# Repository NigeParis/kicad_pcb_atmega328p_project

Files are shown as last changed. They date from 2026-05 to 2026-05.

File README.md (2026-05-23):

# Schematic Bill of Materials

| Reference | Qty | Value | Footprint | Datasheet |
|---|-----|---|---|---|
| C1, C2 | 2 | 12 pF | SMD_603 | [Yageo X7R](https://yageogroup.com/content/datasheet/asset/file/UPY-GPHC_X7R_6_3V-TO-250V) |
| C3 | 1 | 100 nF | SMD_603 | [Yageo X7R](https://yageogroup.com/content/datasheet/asset/file/UPY-GPHC_X7R_6_3V-TO-250V) |
| C4, C7 | 2 | 100 nF | SMD_603 | [Yageo X7R](https://yageogroup.com/content/datasheet/asset/file/UPY-GPHC_X7R_6_3V-TO-250V) |
| C6 | 1 | 1 µF | SMD_603 | [Yageo X7R](https://yageogroup.com/content/datasheet/asset/file/UPY-GPHC_X7R_6_3V-TO-250V) |
| D1 | 1 | LED Green | SMD_603 | [KP-1608ID](https://cdn-reichelt.de/documents/datenblatt/A500/KP-1608ID(VER.9A).pdf) |
| D2 | 1 | LED Red | SMD_603 | [KP-1608ID](https://cdn-reichelt.de/documents/datenblatt/A500/KP-1608ID(VER.9A).pdf) |
| J1 | 1 | Connector | J1_connector | [Samtec TSW](https://suddendocs.samtec.com/catalog_english/tsw_th.pdf) |
| J2 | 1 | Connector | J2_connector | [Samtec TSW](https://suddendocs.samtec.com/catalog_english/tsw_th.pdf) |
| J3 | 1 | FTDI | TSW-106-08-L-S-RA | [Samtec TSW](https://suddendocs.samtec.com/catalog_english/tsw_th.pdf) |
| R1 | 1 | 330 Ω | SMD_603 | [Yageo RC](https://yageogroup.com/content/datasheet/asset/file/PYU-RC_GROUP_51_ROHS_L) |
| R2, R3 | 2 | 10 kΩ | SMD_603 | [Yageo RC](https://yageogroup.com/content/datasheet/asset/file/PYU-RC_GROUP_51_ROHS_L) |
| SW1 | 1 | Push Switch | B3U-1000P(M) | [Omron B3U](https://omronfs.omron.com/en_US/ecb/products/pdf/en-b3u.pdf) |
| U1 | 1 | ATmega328P-A | TQFP-32 | [Microchip](https://ww1.microchip.com/downloads/aemDocuments/documents/corporate-responsibilty/environmental/material-compliance-documents/32L_TQFP_7x7x1_0mm_PT_C04-00074c.pdf) |
| Y1 | 1 | 16 MHz Crystal | SMD3225-4P | [X322516MLB4SI](https://www.lcsc.com/datasheet/C13738.pdf) |

## Summary

| Category | Count |
|---|---|
| Capacitors (C) | 6 |
| Diodes / LEDs (D) | 2 |
| Connectors (J) | 3 |
| Resistors (R) | 3 |
| Switch (SW) | 1 |
| Microcontroller (U) | 1 |
| Crystal (Y) | 1 |
| **Total components** | **17** |

# Pinout — Schematic (ATmega328P-A)

## J1 (12-pin, left connector)

| Pin | Signal |
|-----|---|
| 12  | TXO |
| 11  | RXI |
| 10  | RST |
| 9 | GND |
| 8 | D2 |
| 7 | D3 |
| 6 | D4 |
| 5 | D5 |
| 4 | D6 |
| 3 | D7 |
| 2 | D8 |
| 1 | D9 |

---

## J2 (12-pin, right connector)

| Pin | Signal |
|-----|---|
| 1 | RAW |
| 2 | GND |
| 3 | RST |
| 4 | VCC |
| 5 | A3 |
| 6 | A2 |
| 7 | A1 |
| 8 | A0 |
| 9 | SCK |
| 10  | MISO |
| 11  | MOSI |
| 12  | D10 |

---

## J3 — FTDI (6-pin)

| Pin | Signal |
|-----|---|
| 6 | GND |
| 5 | GND |
| 4 | VCC |
| 3 | RXI |
| 2 | TXO |
| 1 | DTR |

## 0603 SMD LED

**Imperial:** 0603 | **Metric equivalent:** 1608  
**Dimensions:** 1.6 × 0.8 × 0.8 mm (L × W × H)

### Top View

```
           1.6 mm
   ┌───────────────────┐
   │                   │  0.8 mm
   │   ╔═══════════╗   │
   │   ║    DIE    ║   │
   │   ╚═══════════╝   │
   │                   │
   └───────────────────┘
   [+]              [-]
  Anode           Cathode
```

### Dimensions Summary

| Parameter | Value |
|---|---|
| Length (L) | 1.6 mm |
| Width (W) | 0.8 mm |
| Height (H) | 0.8 mm |
| Pad size (each)  | ~0.8 × 0.9 mm |
| Pad pitch | ~0.8 mm |

### Notes
- Machine assembly strongly recommended; hand-soldering possible but challenging
- Typical forward current: 20 mA
- Typical forward voltage: 2.0–3.5 V (color-dependent)
- Cathode typically marked with a dot, triangle, or band on the package

Capture d’écran 2026-05-17 à 12 26 42
Capture d’écran 2026-05-17 à 12 28 25

## Soldered another PCB but even smaller </br>
The atmega328P-au was hard to do, had to resolder it 5 times until placed exactly on the pads.</br>
size of the MCU is 7mm x 7mm and 32 pads </br>
example size of a LED 

# SMD LED Package Dimensions: 0402 & 0603

> Imperial package codes — dimensions in **millimeters (mm)**

---

## 0402 SMD LED

**Imperial:** 0402 | **Metric equivalent:** 1005  
**Dimensions:** 1.0 × 0.5 × 0.5 mm (L × W × H)

### Top View

```
        1.0 mm
   ┌─────────────┐
   │             │  0.5 mm
   │  ╔═══════╗  │
   │  ║  DIE  ║  │
   │  ╚═══════╝  │
   │             │
   └─────────────┘
   [+]         [-]
  Anode      Cathode
```

### Dimensions Summary

| Parameter | Value |
|---|---|
| Length (L) | 1.0 mm |
| Width (W) | 0.5 mm |
| Height (H) | 0.5 mm |
| Pad size (each)  | ~0.5 × 0.5 mm |
| Pad pitch | ~0.6 mm |

carte


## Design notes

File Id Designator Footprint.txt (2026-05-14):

"Id";"Designator";"Footprint";"Quantity";"Designation";"Supplier and ref";
1;"C1, C2";"C_0603_1608Metric_Pad1.08x0.95mm_HandSolder";2;"12pF";;;
2;"C3, C4, C7";"C_0603_1608Metric_Pad1.08x0.95mm_HandSolder";3;"100nF";;;
3;"C6";"C_0603_1608Metric_Pad1.08x0.95mm_HandSolder";1;"1uF";;;
4;"D1";"LED_0603_1608Metric_Pad1.05x0.95mm_HandSolder";1;"Green";;;
5;"D2";"LED_0603_1608Metric_Pad1.05x0.95mm_HandSolder";1;"Red";;;

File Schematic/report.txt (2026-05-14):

Change symbol C2 from 'elec:Capacitor' to 'Elec_Nigel:Capacitor_12_pF': OK

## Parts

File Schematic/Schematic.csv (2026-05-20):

Reference | Qty | Value | DNP | Exclude from BOM | Exclude from Board | Footprint | Datasheet
C1,C2 | 2 | 12 pF |  |  |  | Library:SMD_603 | https://yageogroup.com/content/datasheet/asset/file/UPY-GPHC_X7R_6_3V-TO-250V
C3 | 1 | 100 nf |  |  |  | Library:SMD_603 | https://yageogroup.com/content/datasheet/asset/file/UPY-GPHC_X7R_6_3V-TO-250V
C4,C7 | 2 | 100nF |  |  |  | Library:SMD_603 | https://yageogroup.com/content/datasheet/asset/file/UPY-GPHC_X7R_6_3V-TO-250V
C6 | 1 | 1uF |  |  |  | Library:SMD_603 | https://yageogroup.com/content/datasheet/asset/file/UPY-GPHC_X7R_6_3V-TO-250V
D1 | 1 | GREEN |  |  |  | Library:SMD_603 | https://cdn-reichelt.de/documents/datenblatt/A500/KP-1608ID(VER.9A).pdf
D2 | 1 | RED |  |  |  | Library:SMD_603 | https://cdn-reichelt.de/documents/datenblatt/A500/KP-1608ID(VER.9A).pdf
J1 | 1 | ~ |  |  |  | Library:J1_connector | https://suddendocs.samtec.com/catalog_english/tsw_th.pdf
J2 | 1 | ~ |  |  |  | Library:J2_connector | https://suddendocs.samtec.com/catalog_english/tsw_th.pdf
J3 | 1 | FTDI |  |  |  | Library:FDTI_conector_TSW-106-08-L-S-RA | https://suddendocs.samtec.com/catalog_english/tsw_th.pdf
R1 | 1 | 330 |  |  |  | Library:SMD_603 | https://yageogroup.com/content/datasheet/asset/file/PYU-RC_GROUP_51_ROHS_L
R2,R3 | 2 | 10K |  |  |  | Library:SMD_603 | https://yageogroup.com/content/datasheet/asset/file/PYU-RC_GROUP_51_ROHS_L
SW1 | 1 | SW_Push |  |  |  | Library:interupter_SMD_B3U-1000P(M) | https://omronfs.omron.com/en_US/ecb/products/pdf/en-b3u.pdf
U1 | 1 | ATmega328P-A |  |  |  | Library:atMega328P | https://ww1.microchip.com/downloads/aemDocuments/documents/corporate-responsibilty/environmental/material-compliance-documents/32L_TQFP_7x7x1_0mm_PT_C04-00074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
Y1 | 1 | 16 Mhz |  |  |  | Library:Oscillator_SMD3225-4P_X322516MLB4SI | https://www.lcsc.com/datasheet/C13738.pdf

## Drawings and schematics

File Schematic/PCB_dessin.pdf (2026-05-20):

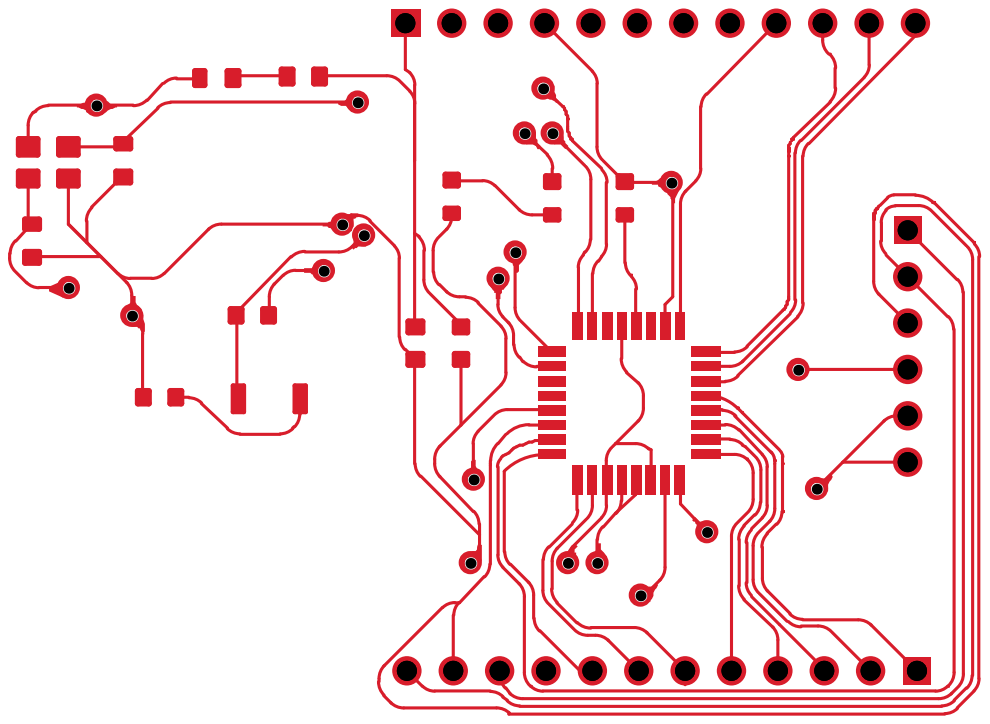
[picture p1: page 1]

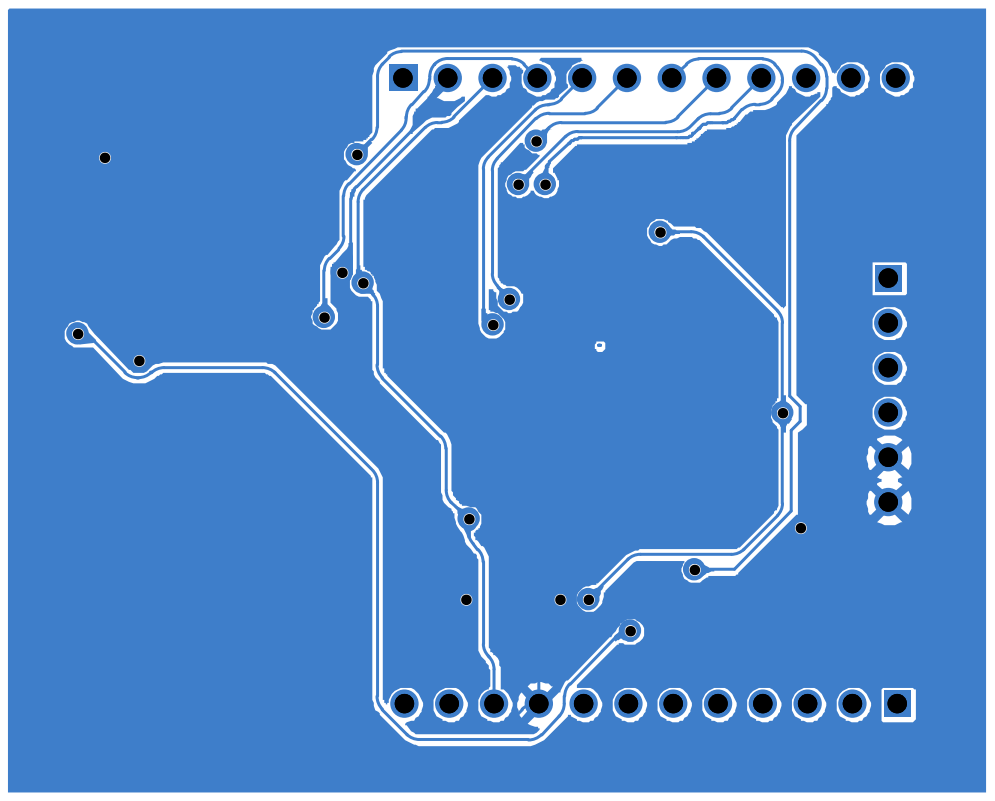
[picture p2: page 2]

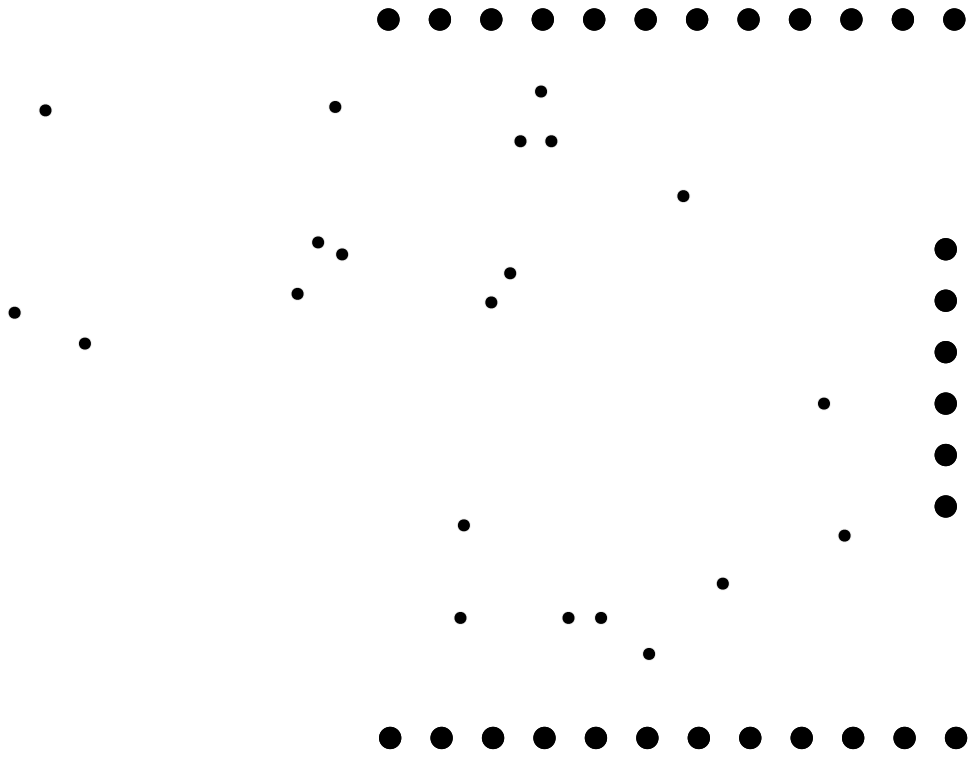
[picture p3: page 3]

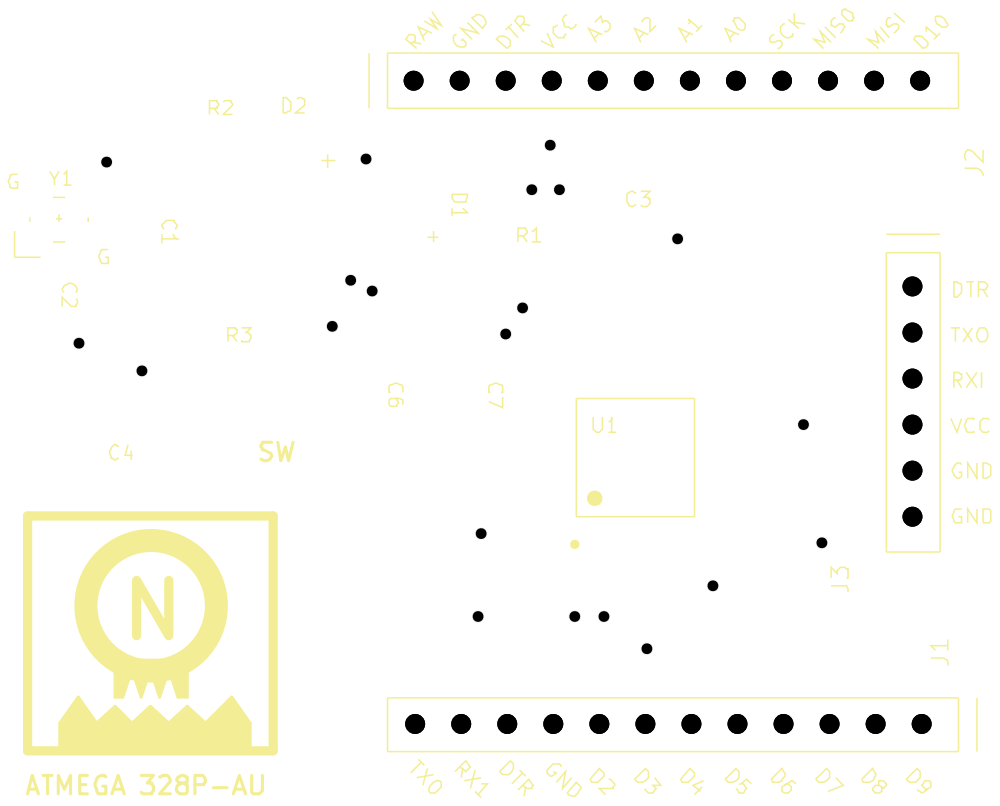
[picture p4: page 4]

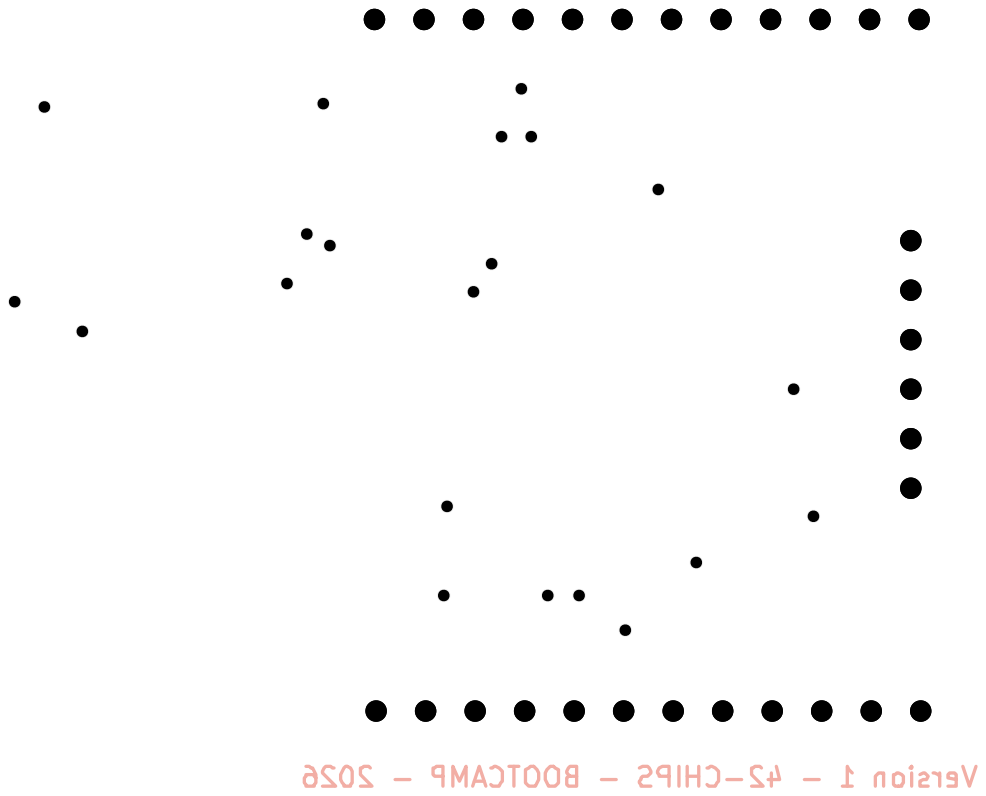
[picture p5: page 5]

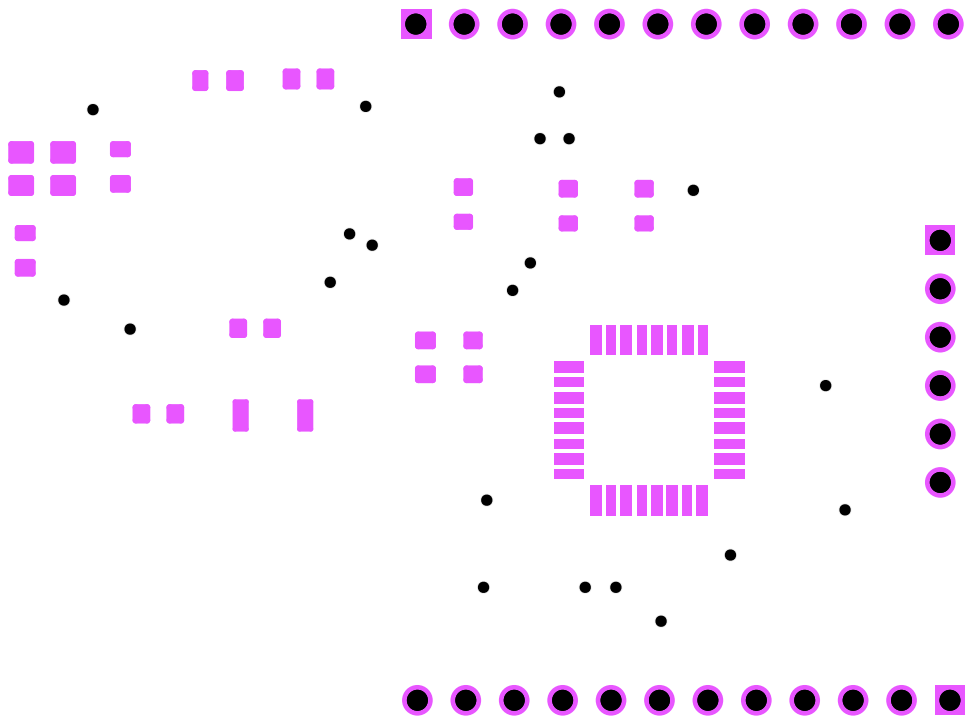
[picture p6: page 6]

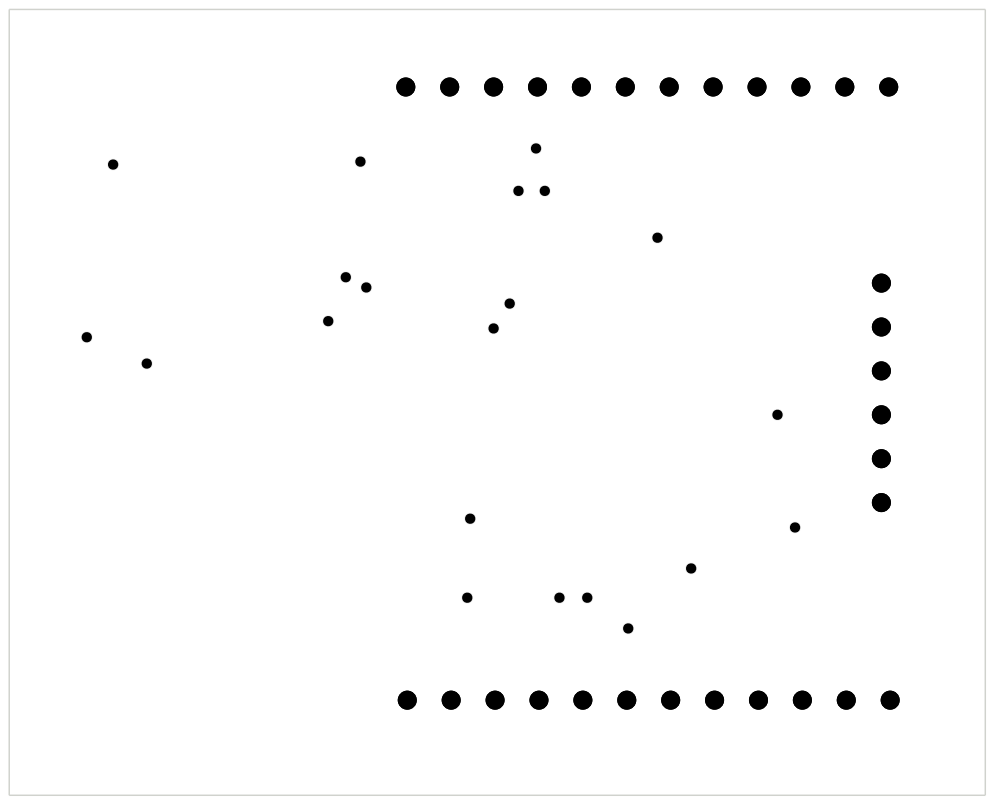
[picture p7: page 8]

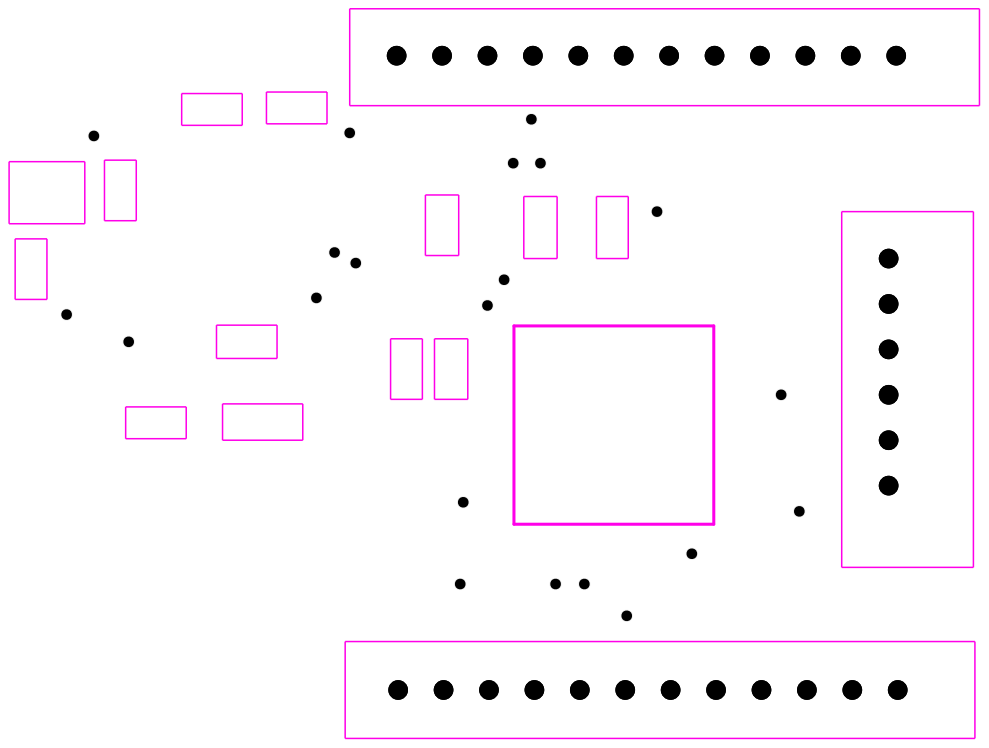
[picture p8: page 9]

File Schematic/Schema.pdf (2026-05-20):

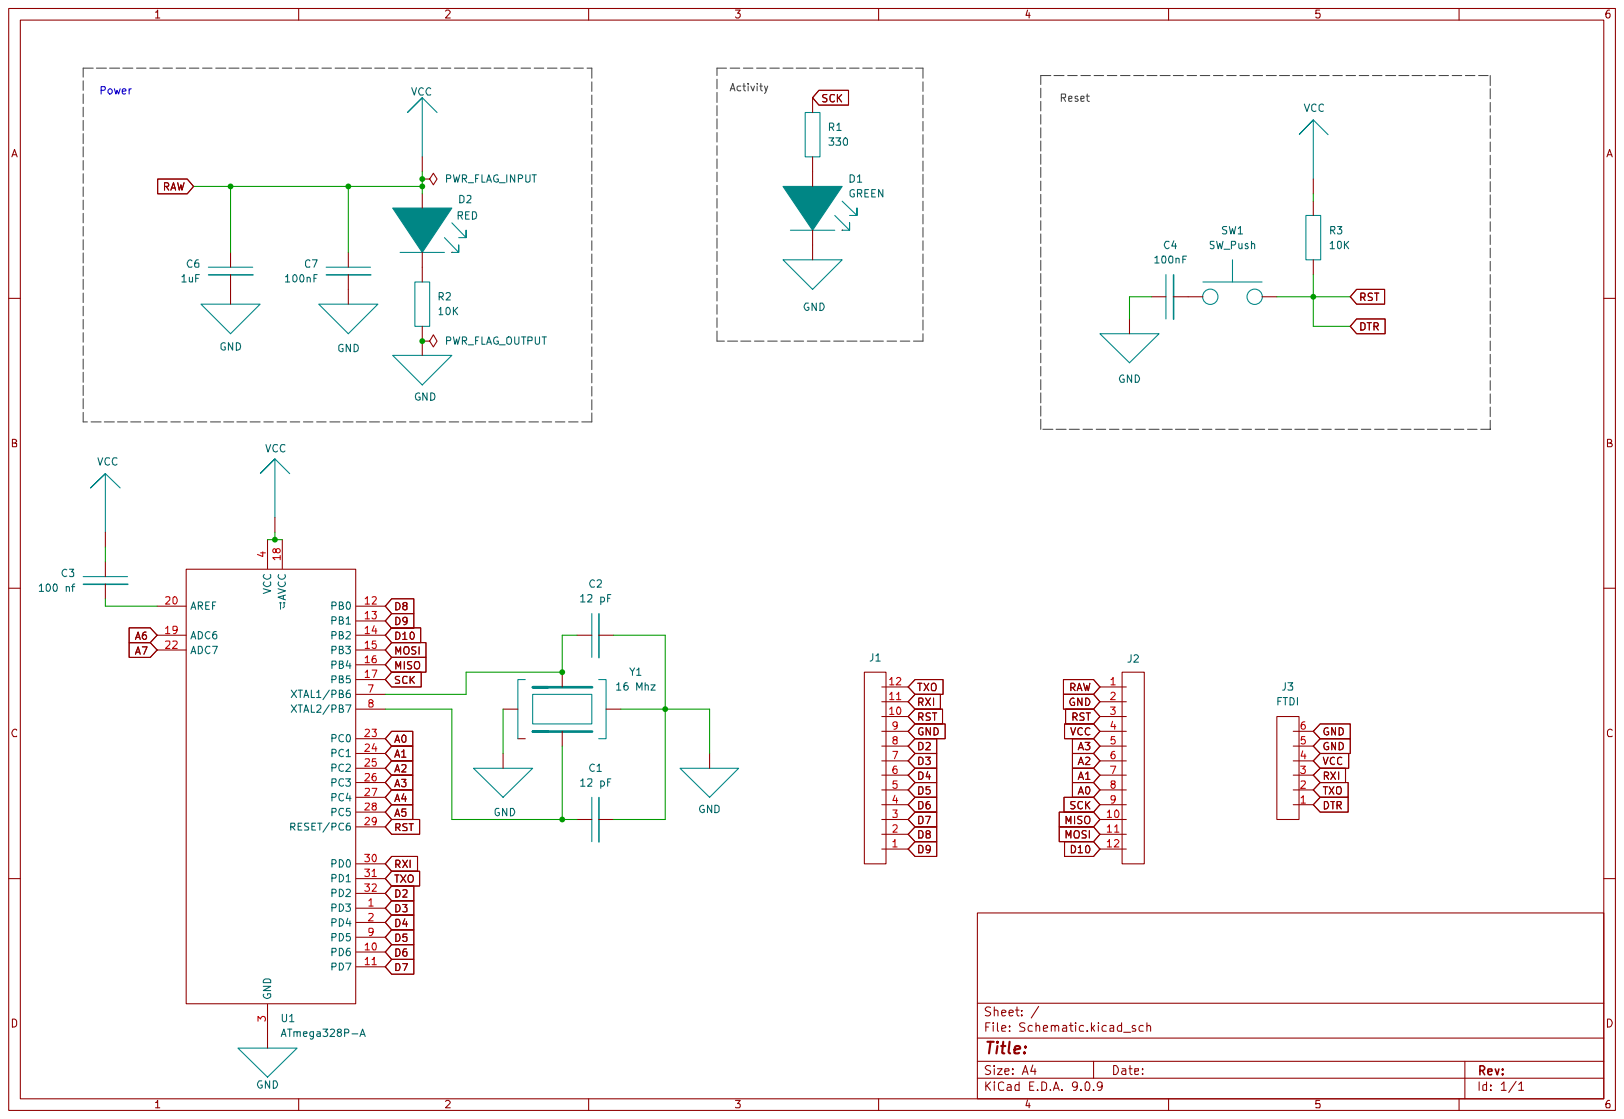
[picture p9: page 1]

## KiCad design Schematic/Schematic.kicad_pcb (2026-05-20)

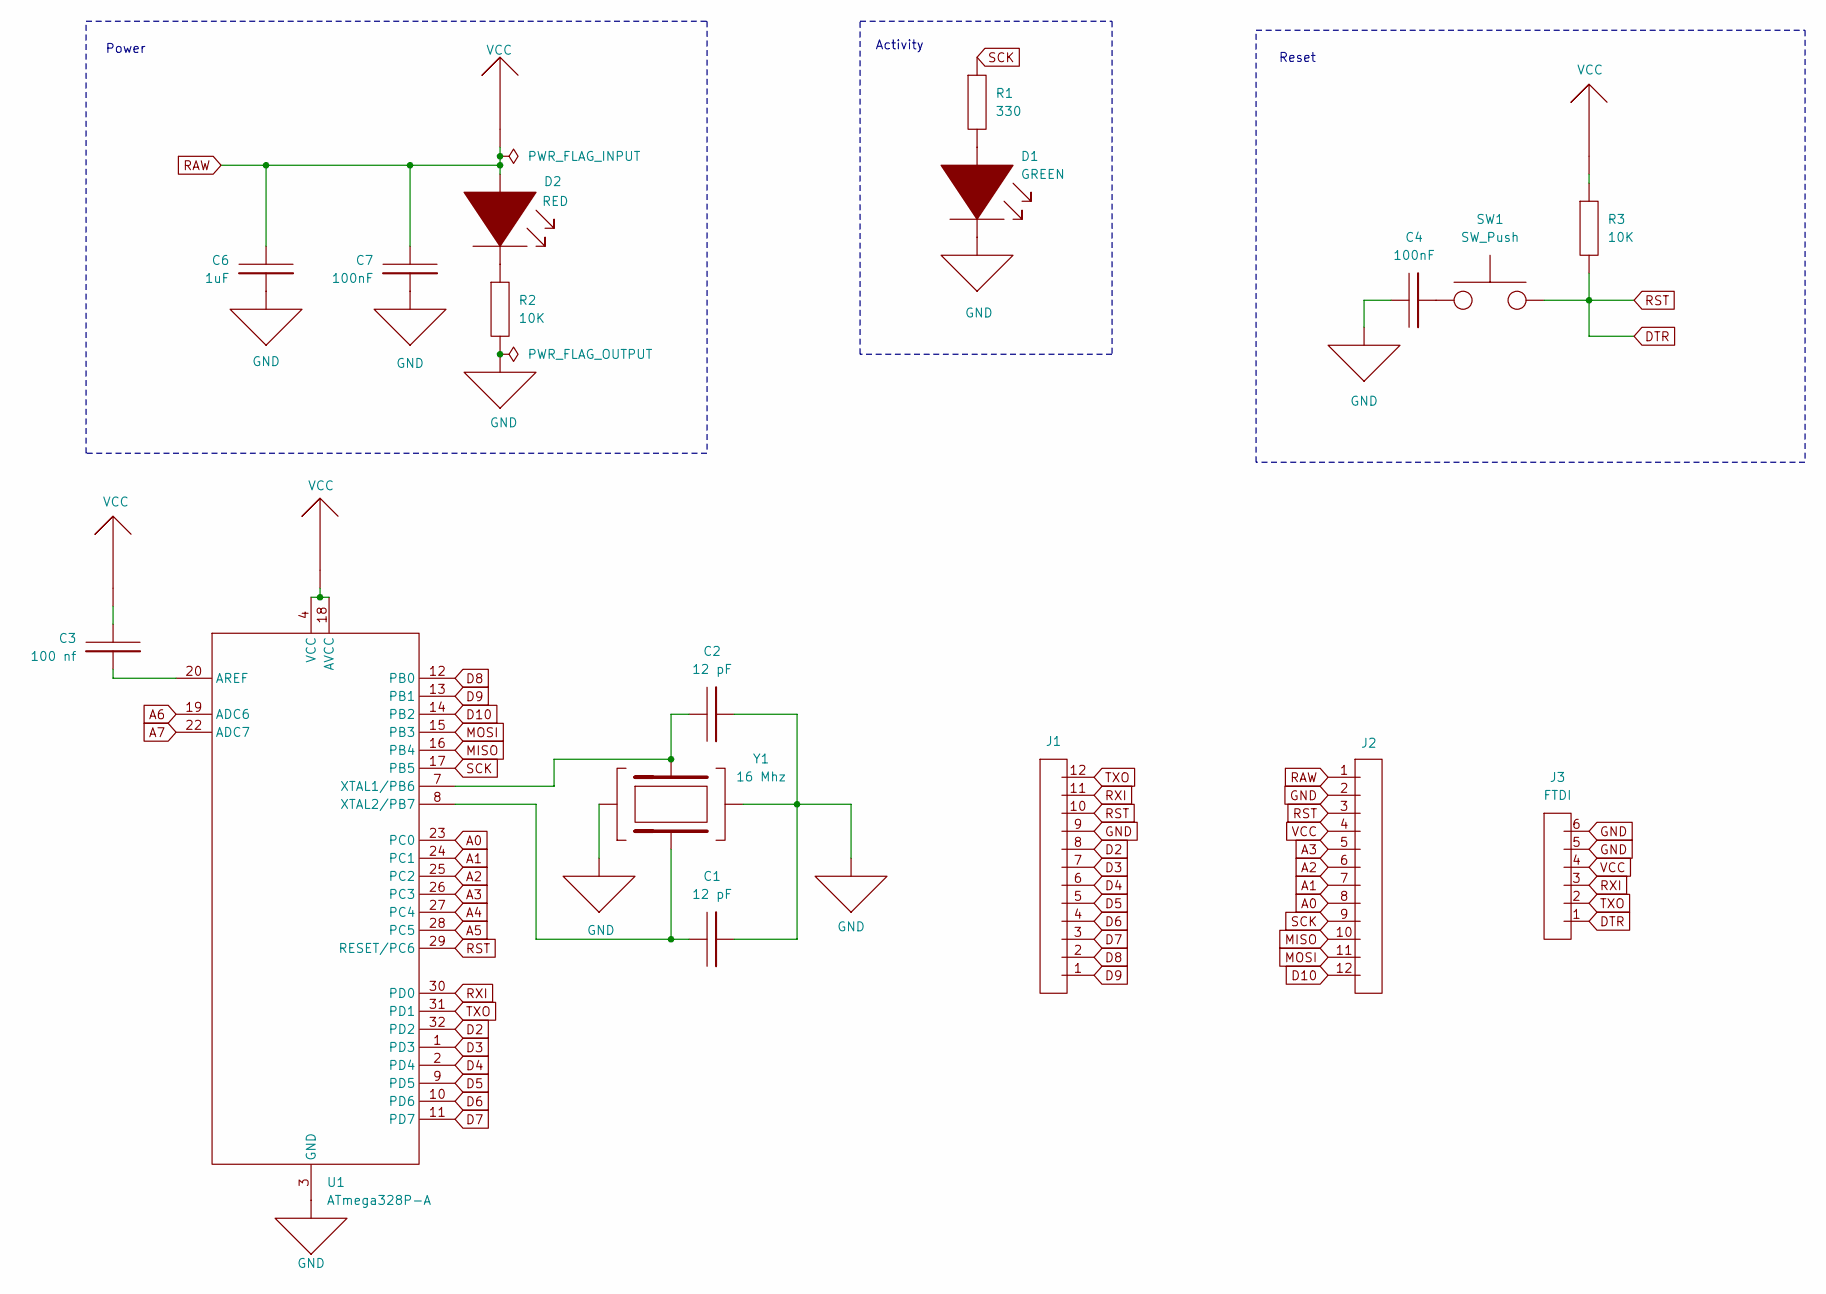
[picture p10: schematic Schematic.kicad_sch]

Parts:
C1, C2: 12 pF; SMD_603
C3: 100 nf; SMD_603
C4, C7: 100nF; SMD_603
C6: 1uF; SMD_603
D1: GREEN; SMD_603
D2: RED; SMD_603
J1: J1_connector
J2: J2_connector
J3: FTDI; FDTI_conector_TSW-106-08-L-S-RA
R1: 330; SMD_603
R2, R3: 10K; SMD_603
SW1: SW_Push; interupter_SMD_B3U-1000P(M)
U1: ATmega328P-A; atMega328P
Y1: 16 Mhz; Oscillator_SMD3225-4P_X322516MLB4SI

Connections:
A0: J2.8, U1.23 (PC0)
A1: J2.7, U1.24 (PC1)
A2: J2.6, U1.25 (PC2)
A3: J2.5, U1.26 (PC3)
A4: U1.27 (PC4)
A5: U1.28 (PC5)
A6: U1.19 (ADC6)
A7: U1.22 (ADC7)
D2: J1.8, U1.32 (PD2)
D3: J1.7, U1.1 (PD3)
D4: J1.6, U1.2 (PD4)
D5: J1.5, U1.9 (PD5)
D6: J1.4, U1.10 (PD6)
D7: J1.3, U1.11 (PD7)
D8: J1.2, U1.12 (PB0)
D9: J1.1, U1.13 (PB1)
D10: J2.12, U1.14 (PB2)
DTR: J1.10, J2.3, J3.1, R3.2, SW1.2, U1.29 (RESET/PC6)
GND: C1.2, C2.2, C4.1, C6.2 (GND), C7.2, D1.2, J1.9, J2.2, J3.5, J3.6, R2.2, U1.3 (GND), U1.5, U1.21, Y1.2, Y1.4
MISO: J2.10, U1.16 (PB4)
MOSI: J2.11, U1.15 (PB3)
unnamed: C4.2, SW1.1
unnamed: D1.1, R1.2
unnamed: D2.2, R2.1
unnamed: C3.2, U1.20 (AREF)
unnamed: C2.1, U1.7 (XTAL1/PB6), Y1.1
unnamed: C1.1, U1.8 (XTAL2/PB7), Y1.3
RXI: J1.11, J3.3, U1.30 (PD0)
SCK: J2.9, R1.1, U1.17 (PB5)
TXO: J1.12, J3.2, U1.31 (PD1)

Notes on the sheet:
Power
Reset
Activity

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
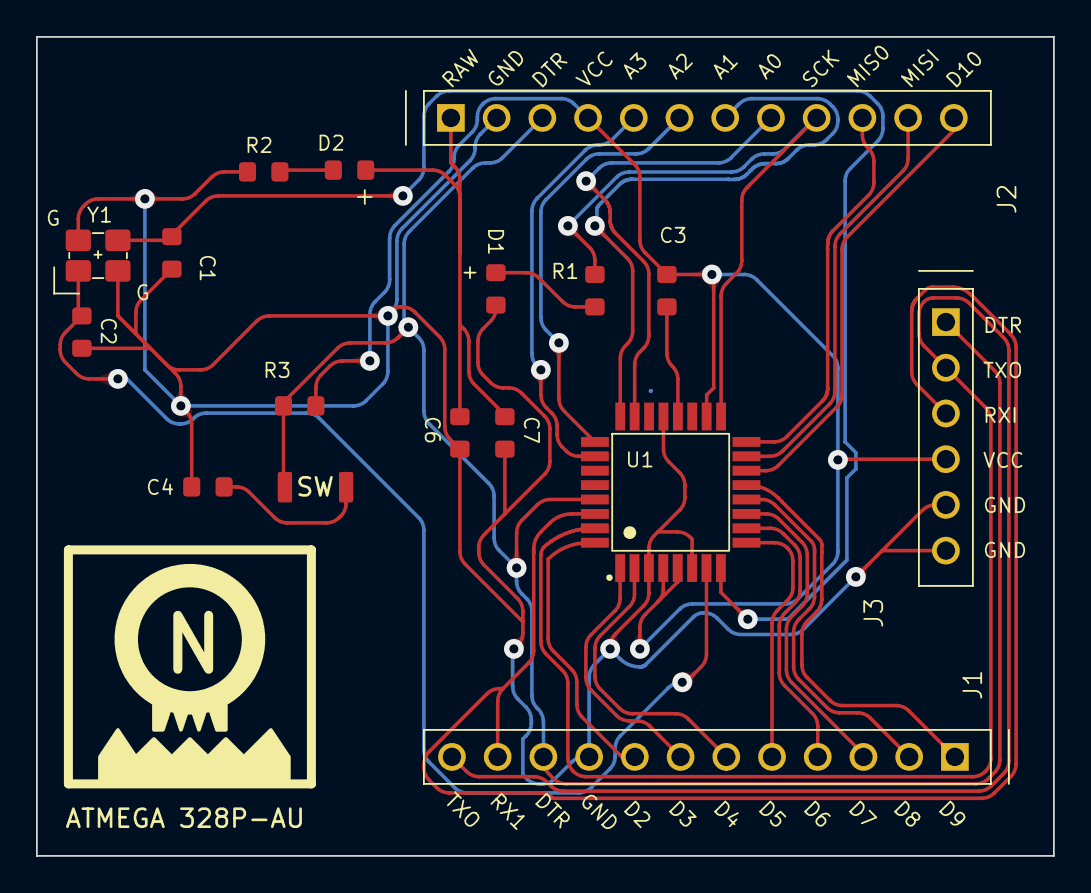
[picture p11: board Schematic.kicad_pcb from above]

Board: 2 copper layers, 56.5 x 45.5 mm, 16 parts (0 on the bottom side), 27 nets.

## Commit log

2026-05-14 New file
    [Schematic.kicad_pcb, Schematic.kicad_sch, file.csv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]
2026-05-14 symbol lib
    [Schematic.kicad_sch]
2026-05-14 error PCB done 12 warning to do
    [Schematic.kicad_pcb, Schematic.kicad_sch]
2026-05-14 warnings still to do
    [Schematic.kicad_pcb, Schematic.kicad_sch]
2026-05-15 pcb working
    [Schematic.kicad_pcb, Schematic.kicad_sch]
2026-05-16 updated board
    [Schematic.kicad_pcb, Schematic.kicad_sch]
2026-05-17 updated silk screen
    [Schematic.kicad_pcb]
2026-05-17 lib update
    [Schematic.kicad_sch]
2026-05-23 Document soldering experience with smaller PCB
    Added a section about soldering a smaller PCB and challenges faced.
2026-05-23 Add 0603 SMD LED specifications to README
    Added detailed specifications and diagrams for the 0603 SMD LED, including dimensions, notes, and top view drawings.
2026-05-23 Document 0402 SMD LED dimensions and drawings
    Added detailed dimensions and top view drawings for 0402 SMD LED package.
